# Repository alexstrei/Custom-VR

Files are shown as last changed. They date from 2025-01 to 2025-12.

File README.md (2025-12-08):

# Custom DIY VR Headset

A fully open, 3D-printable VR headset featuring adjustable IPD, dual-display modules, and integration with **Monado**.  
This repository contains all 3D models, build instructions, and software setup steps required to assemble and run the headset.

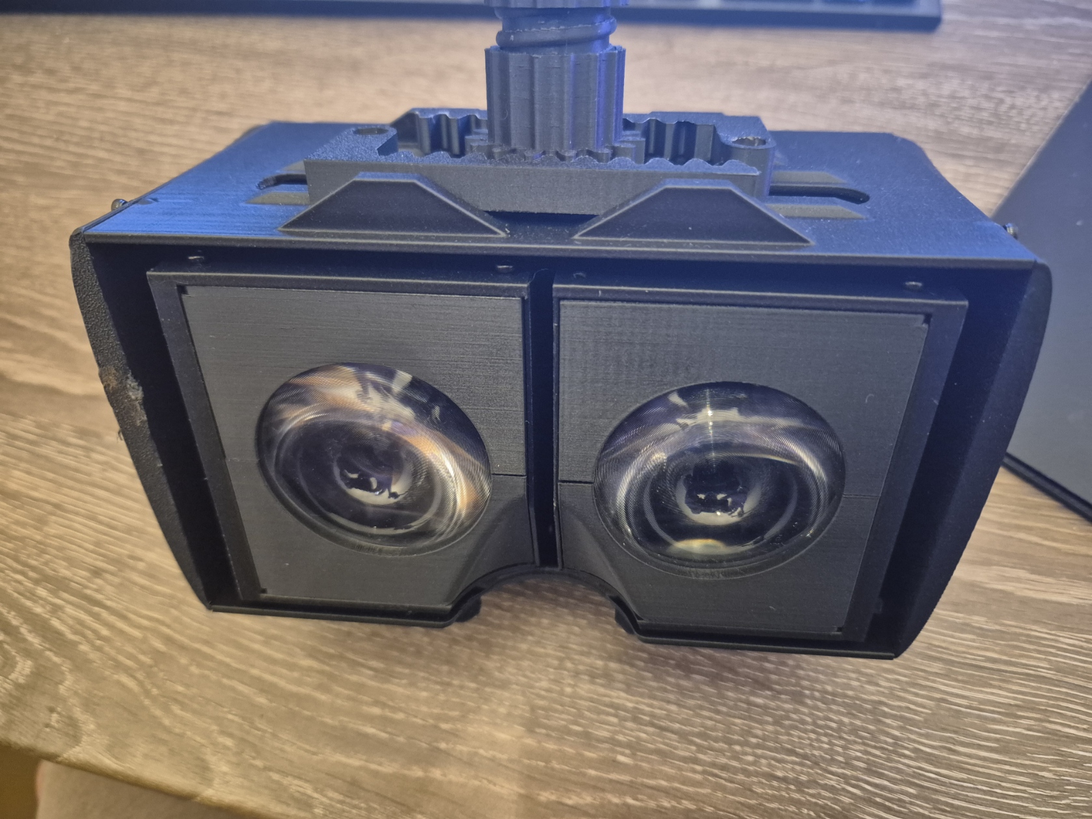
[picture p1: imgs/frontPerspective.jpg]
Front of the Headset


---

## Project Overview

This project provides:
- A **hardware design** for a custom VR headset  
- Integration of a **Custom VR** driver in Monado ([Original Project](https://gitlab.freedesktop.org/monado/monado)
---)
- Compiled binaries for [Basalt](https://github.com/CIFASIS/basalt-xr)
---

## Required Tools

 - 3D printer 
 - Metal saw 
 - Heat source (lighter, etc.)
 - Soldering iron

---

## Required Purchased Parts

These parts are used across the headset, primarily for the eye modules.

| Part | Count | Product ID | Vendor |
|---|---|---|---|
| Threaded Rod M3, 55 mm | 4 | B0D5DGMXNN | Amazon |
| Press Insert M3 | 4 | B0CRYWCYMG | Amazon |
| Allen Screw M2 x 4 mm | 40 | B0CKN2VK12 | Amazon |
| Press Insert M2 | 41 | B0CRYWCYMG | Amazon |
| Allen Screw M2 x 6 mm | 1 | B0CKN2VK12 | Amazon |
| Display + Breakout Board | 2 | 1005008477815602 | AliExpress |
| MIPI-to-HDMI Board | 2 | 1005008477815602 | AliExpress |

---

## Assembly 

An assembly video can be seen here: https://youtu.be/JpesEXfNubU but it still needs commentary.
Image of lens module can be seen here.
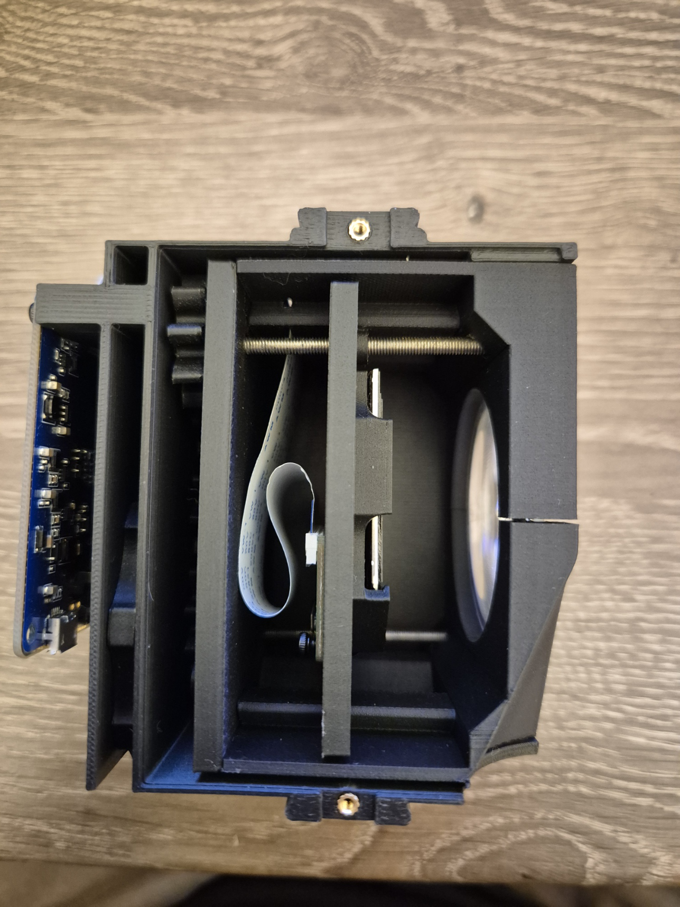
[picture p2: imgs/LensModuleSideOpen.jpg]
Lens Module


## Project Status

This is an experimental hardware project intended for research, education, and VR hacking.  
Contributions and improvements are welcome.

---

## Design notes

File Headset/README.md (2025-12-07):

# Printable Headset

The f3z file is for importing and editing the piece in Fusion360. The 3mf file is for 3D printing as it contains all the models.

# Images of the Final Headset

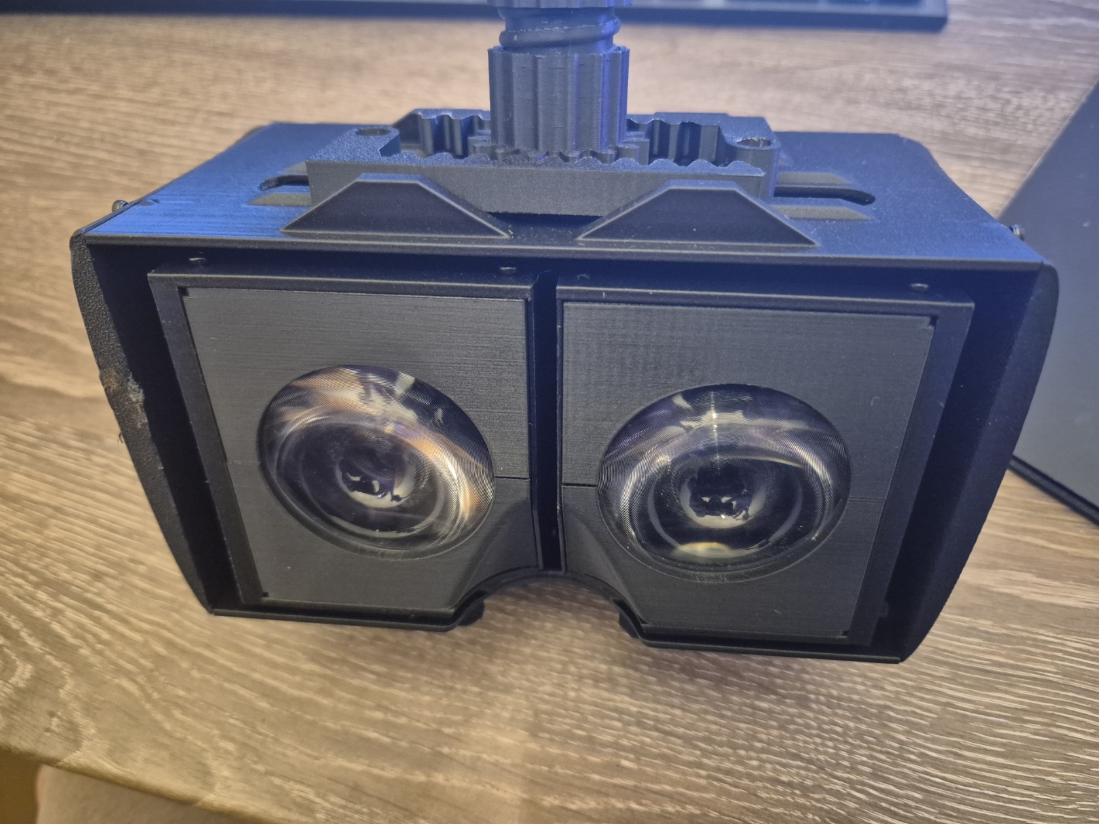
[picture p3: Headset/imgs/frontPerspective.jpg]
Full Headset

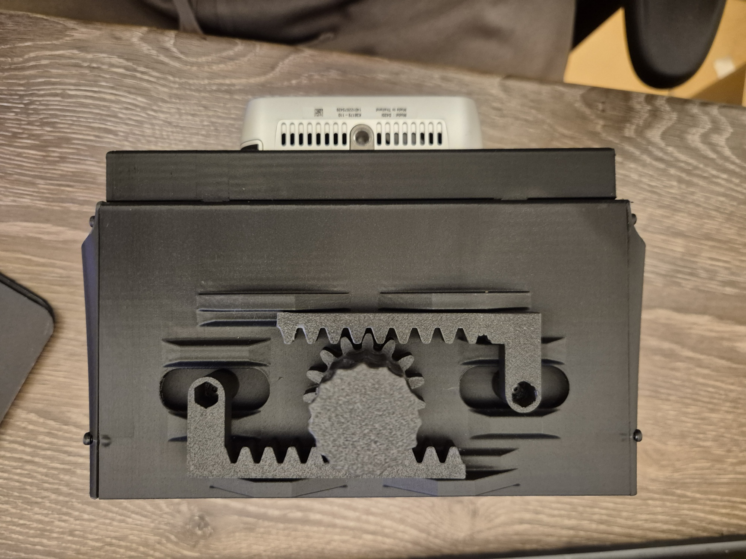
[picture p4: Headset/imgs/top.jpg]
Top of the Headset

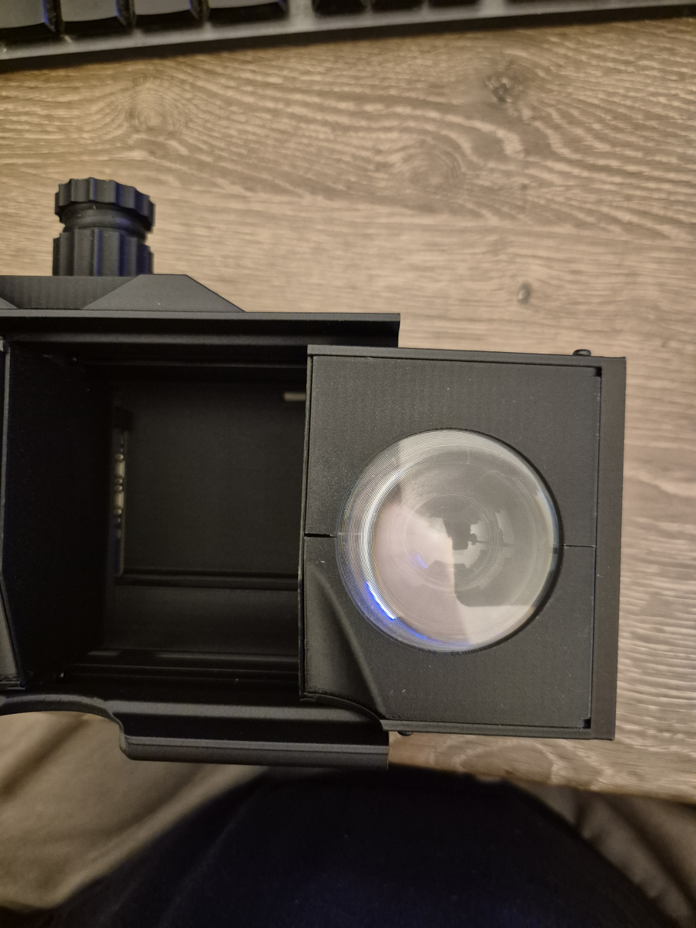
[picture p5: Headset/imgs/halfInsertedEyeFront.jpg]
Half inserted Eye module

Eye module

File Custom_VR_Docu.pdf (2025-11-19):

# Custom VR

This Document provides instructions for creating the custom VR headset described in the previous chapters. It begins by listing the required parts for each assembly step and provides detailed instructions for building the hardware. A description of the compilation process for Monado follows this. Since Monado does not run as expected by simply starting the program, the necessary environment variables are listed. Finally, if game support via SteamVR is desired, this chapter also includes an explanation of the required modifications.

## 1 Assembling the Headset

To create a new headset, a 3D printer, a Metal Saw, a lighter, or other source of heat, and a soldering iron are required. In Table 1, the parts that need to be purchased are listed. For 3D printing, a total of 39 parts need to be printed, 10 for each eye module, 8 for the case, and 1 for the electronics compartment. The assembly process is divided into two parts. The first describes the construction of the left eye module, which can also be used for the right eye module. For the second part, the full assembly of the case with the eye modules and the electronic compartment is described.

### 1.1 Eye Module

In Table 2, the required parts for the headset are listed, and in Figure 1, the 3D printed parts are listed and enumerated. The first step is to prepare the threaded rods. Using a metal saw, cut a 3mm deep line in the center of the

PartN | Count | Product ID
Threaded Rod M3 55mm | 4 | B0D5DGMXNN (Amazon)
Press Insert M3 | 4 | B0CRYWCYMG (Amazon)
Allen Screw M2 4mm | 40 | B0CKN2VK12 (Amazon)
Press Insert M2 | 41 | B0CRYWCYMG (Amazon)
Allen Screw M2 6mm | 1 | B0CKN2VK12 (Amazon)
Display with Breackoutboard | 2 | 1005008477815602 (AliExpress)
MIPI-to-HDMI Board | 2 | 1005008477815602 (AliExpress)

Table 1: Components which need to be bought with their corresponding Product ID and vendor

1

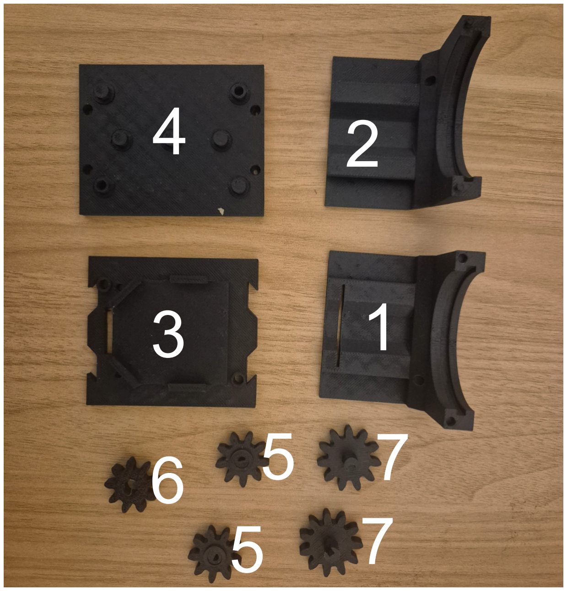
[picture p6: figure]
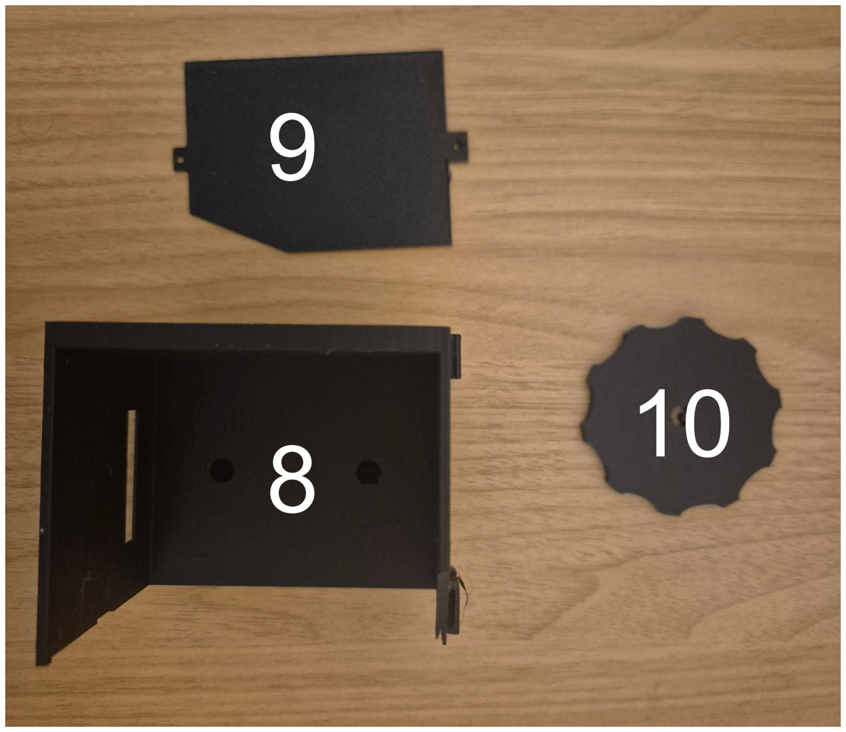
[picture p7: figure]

(a) Inner Module | (b) Outer Module

Figure 1: 3D printed Parts for the eye module with an enumeration

front side of the rod. This cut divides one end of the rod into two halves. Remove one half so that a 3 mm high semicircle remains, connected to the rest of the threaded rod. This semicircle is used to connect to part 5 and transfer the rotational movement from the gear to the threaded rod. By heating the cut end, the rod can be pressed into the semicircular hole in the center of part 5. The heated metal will slightly melt the plastic, allowing it to deform and form tightly around the metal for a secure fit. This process is done twice, once for each part 5. The press inserts can then be mounted on the 3D-printed parts. It is important to press them straight, otherwise the screws may sit crooked or, in the worst case, not fit at all. Parts 1 and 2 each require four M2 inserts, marked by small holes on the bottom and the side. Part 3 requires two M2 and two M3 inserts: M3 inserts for the threaded rods and M2 inserts for securing the breakout board. Part 8 requires six M2 inserts, three in the back for the MIPI-to-HDMI board, two to hold the side cover, and one in the top for the connection to the IPD mechanism.
With the preparations completed, the assembly can begin. First, the display is slid into the bracket in part 3 and the breakout board is mounted on the back.
Part | Count
3D Printed Parts | 10
Threaded Rod M3 55mm | 2
Press Insert M3 | 2
Allen Screw M2 4mm | 15
Press Insert M2 | 16
Display with Breackoutboard | 1
MIPI-to-HDMI Board | 1

Table 2: Parts for one Eye module

2

Part | Count
3D Printed Parts | 9
Allen Screw M2 4mm | 10
Press Insert M2 | 9
Allen Screw M2 6mm | 1

Table 3: Parts for one Eye module

The display and breakout board are then connected through the opening in part
3. Next, part 2 is prepared by placing the lens inside, and part 1 is placed on top of the lens. Part 2 must be positioned below part 1 because it has a small cutout to route the connection cable from the breakout board to the outside. The prepared part 3 is then slid into parts 1 and 2 using the dovetail slides. The connection cable passes through the slit, and part 4 is mounted on the back of parts 1 and 2 to secure the assembly, using four screws. Now, screw both part 5 gears with the threaded rod into the two holes of part 4, which should align with the M3 insert in part 3. Now, screw the gears in until the gears sit flush on part 4. Also, make sure that part 3 is not tilted and is parallel to the lens. Now place part 6 on the middle bump of part 4, and one part 7 on the bump above.
The parts of the surrounding shell are shown in Figure 1 b. This shell encloses the assembled module, blocks out external light, mounts the HDMIto-MIPI board, and connects the module to the main case. This is the most challenging part of the assembly process.
First, part 10 is placed in the smaller compartment in the back of part 8 and secured through the hole with the second part 7 gear. The previously assembled module is then slid into the prepared part 8 with all gears already in place. During sliding, the cable must be routed through the opening on top of part 8. Once the module is almost fully inserted, there is a good chance that the part 7 gear holding part 10 will not align with the gears on part 4. By gently moving part 10 while pressing the assembly together, part 7 will engage correctly with the inner gear system.
Once aligned, the assembly is secured in place by inserting two screws into the top and bottom front of part 8, which are positioned directly above and below the lens. Then Part 9 is placed and screwed onto the side of the module, sealing the shell. For the final step, the HDMI-to-MIPI board is mounted to the back of the assembly, and the cable from the breakout board is connected. The eye module is now fully assembled and ready for use. To build the module for the opposite side, the same steps are followed, but the process is mirrored.

### 1.2 Case and Electronics Compartment

In Table 3, the required parts for the case are listed, and the required 3D printed parts are enumerated in Figure 2. As with previous assemblies, the first step is

3

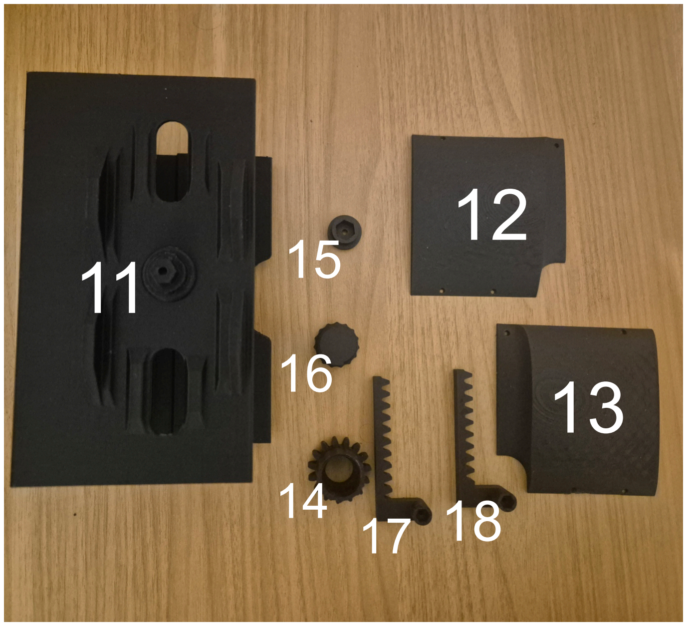
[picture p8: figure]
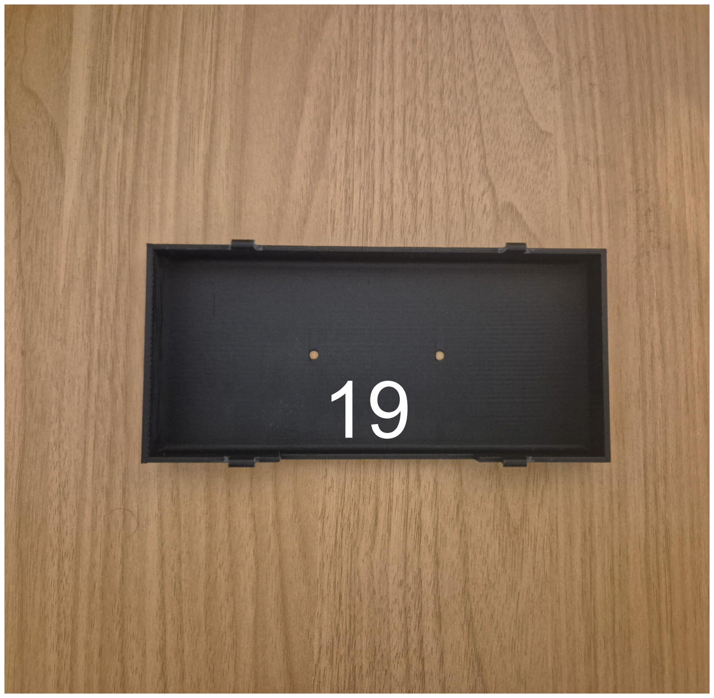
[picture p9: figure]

19 (a) Case Parts | (b) Electronics Compartment

Figure 2: 3D printed Parts for the case and the Electronics Compartment

to prepare the parts for mounting. This means inserting all necessary threaded inserts before doing any other work. In this case, only part 11 requires threaded inserts. Four inserts are needed on each side to mount the side panels, and one insert is placed on top, centered on the bump. With this, the preparation for the case assembly is complete.
First, the two eye modules are inserted into the left and right sides of part
11. To secure them, the left and right panels (parts 12 and 13) are mounted on their respective sides. It is important to check that both modules can move freely and do not bind to the dovetail slides during adjustment.
For the IPD adjustment mechanism, part 17 is placed on top of the device. The higher side is inserted through the left hole and onto the top of the left eye module, where a hexagonal knob serves as the mounting point. The same process is repeated on the right side with part 18. Each connection point is secured with an M2 × 4 mm screw. After moving both modules so that they meet in the center, part 14 is placed on the center bump at the top of the case, enabling synchronized movement of both modules by turning the gear. Next, part 15 is inserted and fixed using an M2 × 6 mm screw, which is threaded into the prepared insert—this is the only step that uses a different screw size. Then, part 16 is screwed into part 14 so that, when tightened, it presses against part 15 and creates a friction joint. Because part 15 has a hexagonal connection point, it cannot rotate, which ensures that the entire IPD mechanism is locked in place. Part 19 can be clipped on the backside of the device. It features two holes in which a camera can be mounted. The headset is now fully assembled and can be plugged into a PC with HDMI and USB cables.

## 2 Compiling Monado for Windows

The first challenge to overcome is compiling Monado for Windows. For this, the Visual Studio 2022 compiler (MSVC) and the CMake build system were

4

installed and used. For dependency management, VCPKG should be used. It is a cross-platform package manager for C++ dependencies. Fortunately, VCPKG is fully integrated into the project, so CMake handles dependency management. The required dependencies for Windows are illustrated in Table 4.
With this in place, CMake successfully generates the project files, allowing the build process to begin. However, this leads to compilation errors, as the entire project was originally based on a Linux compiler. Unfortunately, the standard libraries differ slightly, which caused the initial compilation to fail due to M PI being undefined. This issue can be quickly resolved by adding the line: #define M PI (3.14159265358979323846). After this addition, the compilation process completes successfully, and the system can be started for the first time.

## 3 Starting the System

By building and executing the ”monado service” target, the service can be started and used. However, at this stage, neither a device instance is created nor is the camera detected correctly. The reason for this is the absence of certain required environment variables (see Table 5).
The first variable is responsible for creating an instance of the custom VR device on startup. This is achieved by disabling automatic probing and implicitly registering the device in the system. The second variable is required for the RealSense driver. To correctly identify the connected cameras, the prober must be assigned a valid source index. Without this, the system crashes during startup due to missing stream configuration parameters.
For the SLAM library, two additional environment variables are necessary. One defines the path to the SLAM library, in this case the Basalt library. The other specifies the configuration file for the D435i. Basalt requires this configuration file to operate correctly, as it contains essential parameters such as camera intrinsics, resolution, IMU biases, standard deviations, and other calibration data. These values can be extracted from the camera itself using the RealSense
Dependecie name | Description
Eigen 3.x | linear algebra library
Pthreads Windows | POSIX threading header for Windows
SDL | access to mouse, keyboard, and other peripherals
Vulkan | Graphic API
HIDAPI | Bluetooth and USB interface
LibUSB | For USB device access
cJSON | JSON parser for C
WIL | For easier Windows development

Table 4: This Table lists the required dependencies for Monado along with a brief description of their general purpose. These dependencies must be installed to allow CMake to generate the necessary build files successfully.

5

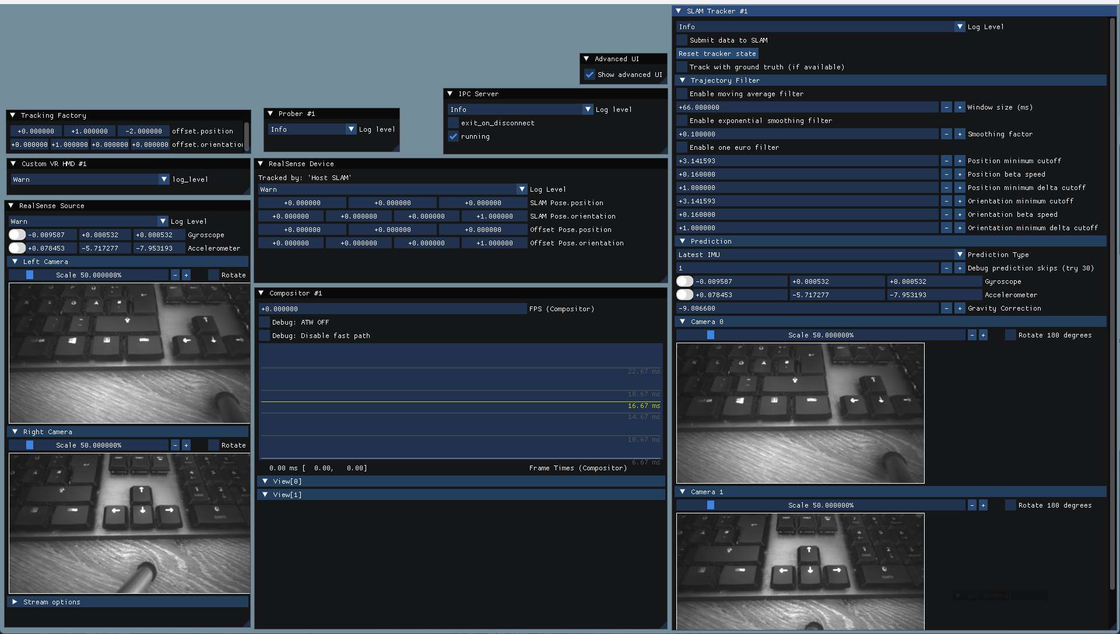
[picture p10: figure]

Figure 3: This image shows the monado UI consisting of multiple windows.

Name | Value
CUSTOM VR ENABLE | 1
RS SOURCE INDEX | 0
SLAM CONFIG | ./d435i.toml
VIT SYSTEM LIBRARY PATH | ./basalt.dll
XRT DEBUG GUI | 1

Table 5: Environment variables for starting monado properly. The first one is for instantiating the headset. Second for the streaming index of the camera, third and fourth for the slam configuration and the last one to enable the debug gui.

camera calibration tool. For the IMU-specific statistical values, a pre-generated configuration file tailored for the D435i was used. The last environment variable enables the use of the debug GUI, shown in Figure 3. This interface was created using ImuGUI and provides controls and statistics for various features within Monado. Several windows within the UI are handy and have been frequently utilized during development.

## 4 Configuring Environment

To inform OpenXR runtime that our platform exists and that we intend to use it
as our standard value, the registry must be edited. In Computer\HKEY LOCAL MACHINE \SOFTWARE\Khronos\OpenXR\1 the path to the file openxr monado-dev.json
must be set. This file is generated during the application build and resides in

6

the binaries directory. It has all the necessary values for the OpenXR loader to load an OpenXR application with the Monado runtime.
With this setup, it is possible to start VR programs from Unity, which then are displayed by Monado. For Steam gaming, there is a bit more setup involved. First of all, the Steam plugin needs to be compiled.
This is done by compiling the ”driver monado” target. This creates a new file in the steamvr-monado/bin including the monado driver.dll which is the plugin for Steam. With this plugin, the driver now needs to be registered on Steam. This is done with a separate batch file that is shipped with the application. ./steam/steamapps/common/SteamVR/bin/vrpathreg.sh adddriver C:/path/to/dll/monado\_driver.dll let Steam know where the custom VR driver is. The success of the command can be verified by running vrpathreg.sh without any parameters. This enables the use of all hardware supported by Monado on Steam, but does not allow for playing games.
To enable game support, the OpenComposite application must be installed. It is responsible for forwarding the SteamVR calls to OpenXR. wBy starting the program and clicking on the ”Switch to OpenVR” button, the redirect is set in place. For the last step, a file in the game needs to be changed to work. Somewhere in the game directory, there is a file called openvr api.dll . The OpenComposite repository provides a replacement file that needs to be swapped out in the game files. With this in place, Monado can be booted up, and then the game can start. This should now open the rendered window. The window can now be placed on top of the two displays to see the rendered view in the headset.

7

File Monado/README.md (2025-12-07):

# Copy of Monado - XR Runtime (XRT)

<!--
Copyright 2018-2021, Collabora, Ltd.

SPDX-License-Identifier: CC-BY-4.0

This must stay in sync with the last section!
-->
This project is copied from Monado (links are below) and modified by myself.

Please note 
> * Main homepage and documentation: <https://monado.freedesktop.org/>
> * Promotional homepage: <https://monado.dev>
> * Maintained at <https://gitlab.freedesktop.org/monado/monado>
> * Latest API documentation: <https://monado.pages.freedesktop.org/monado>
> * Continuously-updated changelog of the default branch:
>   <https://monado.pages.freedesktop.org/monado/_c_h_a_n_g_e_l_o_g.html>

Monado is an open source XR runtime delivering immersive experiences such as VR
and AR on mobile, PC/desktop, and any other device
(because gosh darn people
come up with a lot of weird hardware).
Monado aims to be a complete and conforming implementation
of the OpenXR API made by Khronos.
The project is primarily developed on GNU/Linux, but also runs on Android and Windows.
"Monado" has no specific meaning and is just a name.

## Monado source tree

* `src/xrt/include` - headers that define the internal interfaces of Monado.
* `src/xrt/compositor` - code for doing distortion and driving the display hardware of a device.
* `src/xrt/auxiliary` - utilities and other larger components.
* `src/xrt/drivers` - hardware drivers.
* `src/xrt/state_trackers/oxr` - OpenXR API implementation.
* `src/xrt/targets` - glue code and build logic to produce final binaries.
* `src/external` - a small collection of external code and headers.

## Getting Started

Dependencies include:

* [CMake][] 3.13 or newer (Note Ubuntu 18.04 only has 3.10)
* Python 3.6 or newer
* Vulkan headers and loader - Fedora package `vulkan-loader-devel`
* OpenGL headers
* Eigen3 - Debian/Ubuntu package `libeigen3-dev`
* glslangValidator - Debian/Ubuntu package `glslang-tools`, Fedora package `glslang`.
* libusb
* libudev - Debian/Ubuntu package `libudev-dev`, Fedora package `systemd-devel`
* Video 4 Linux - Debian/Ubuntu package `libv4l-dev`.

Optional (but recommended) dependencies:

* libxcb and xcb-xrandr development packages
* [OpenHMD][] 0.3.0 or newer (found using pkg-config)

Truly optional dependencies, useful for some drivers, app support, etc.:

* Doxygen - Debian/Ubuntu package `doxygen` and `graphviz`
* Wayland development packages
* Xlib development packages
* libhidapi - Debian/Ubuntu package `libhidapi-dev`
* OpenCV
* libuvc - Debian/Ubuntu package `libuvc-dev`
* libjpeg
* libbluetooth - Debian/Ubuntu package `libbluetooth-dev`
* libsdl - Debian/Ubuntu package `libsdl2-dev`

Experimental Windows support requires the Vulkan SDK and also needs or works
best with the following vcpkg packages installed:

* pthreads eigen3 libusb hidapi zlib doxygen

If you have a recent [vcpkg](https://vcpkg.io) installed and use the appropriate
CMake toolchain file, the vcpkg manifest in the Monado repository will instruct
vcpkg to locally install the dependencies automatically. The Vulkan SDK
installer should set the `VULKAN_SDK` Windows environment variable to point
at the installation location (for example, `C:/VulkanSDK/1.3.250.1`), though
make sure you open a new terminal (or open the CMake GUI) *after* doing that
install to make sure it is available.

Monado has been tested on these distributions, but is expected to work on almost
any modern distribution.

* Ubuntu 24.04, 22.04, 20.04, (18.04 may not be fully supported)
* Debian 11 `bookworm`, 10 `buster`
  * Up-to-date package lists can be found in our CI config file,
    `.gitlab-ci.yml`
* Archlinux

These distributions include recent-enough versions of all the
software to use direct mode,
without using any external, third-party, or backported
package sources.

See also [Status of DRM Leases][drm-lease]
for more details on specific packages, versions, and commits.

Due to the lack of a OpenGL extension: GL_EXT_memory_object_fd on Intel's
OpenGL driver, only the AMD
radeonsi driver and the proprietary NVIDIA driver will work for OpenGL OpenXR
clients. This is due to a requirement of the Compositor. Support status of the
extension can be found on the [mesamatrix website][mesamatrix-ext].

### CMake

Build process is similar to other CMake builds,
so something like the following will build it.

Go into the source directory, create a build directory,
and change into it.

```bash
mkdir build
cd build
```

Then, invoke [CMake to generate a project][cmake-generate].
Feel free to change the build type or generator ("Ninja" is fast and parallel) as you see fit.

```bash
cmake .. -DCMAKE_BUILD_TYPE=Debug -G "Unix Makefiles"
```

If you plan to install the runtime,
append something like `-DCMAKE_INSTALL_PREFIX=~/.local`
to specify the root of the install directory.
(The default install prefix is `/usr/local`.)

To build, [the generic CMake build commands][cmake-build] below will work on all systems,
though you can manually invoke your build tool (`make`, `ninja`, etc.) if you prefer.
The first command builds the runtime and docs,
and the second, which is optional, installs the runtime under `${CMAKE_INSTALL_PREFIX}`.

```bash
cmake --build .
cmake --build . --target install
```

Alternately, if using Make, the following will build the runtime and docs, then install.
Replace `make` with `ninja` if you used the Ninja generator.

```bash
make
make install
```

Documentation can be browsed by opening `doc/html/index.html` in the build directory in a web browser.

## Getting started using OpenXR with Monado

This implements the [OpenXR][] API,
so to do anything with it, you'll need an application
that uses OpenXR, along with the OpenXR loader.
The OpenXR loader is a glue library that connects OpenXR applications to OpenXR runtimes such as Monado
It determines which runtime to use by looking for the config file `active_runtime.json` (either a symlink to
or a copy of a runtime manifest) in the usual XDG config paths
and processes environment variables such as `XR_RUNTIME_JSON=/usr/share/openxr/0/openxr_monado.json`.
It can also insert OpenXR API Layers without the application or the runtime having to do it.

You can use the `hello_xr` sample provided with the OpenXR SDK.

The OpenXR loader can be pointed to a runtime json file in a nonstandard location with the environment variable `XR_RUNTIME_JSON`. Example:

```bash
XR_RUNTIME_JSON=~/monado/build/openxr_monado-dev.json ./openxr-example
```

For ease of development Monado creates a runtime manifest file in its build directory using an absolute path to the
Monado runtime in the build directory called `openxr_monado-dev.json`. Pointing `XR_RUNTIME_JSON` to this
file allows using Monado after building, without installing.

Note that the loader can always find and load the runtime
if the path to the runtime library given in the json manifest is an absolute path,
but if a relative path like `libopenxr_monado.so.0` is given,
then `LD_LIBRARY_PATH` must include the directory that contains `libopenxr_monado.so.0`.
The absolute path in `openxr_monado-dev.json` takes care of this for you.

Distribution packages for monado may provide the  "active runtime" file `/etc/xdg/openxr/1/active_runtime.json`.
In this case the loader will automatically use Monado when starting an OpenXR application. This global configuration
can be overridden on a per user basis by creating `~/.config/openxr/1/active_runtime.json`.

## Direct mode

On AMD and Intel GPUs our direct mode code requires a connected HMD to have
the `non-desktop` xrandr property set to 1.
Only the most common HMDs have the needed quirks added to the linux kernel.

If you know that your HMD lacks the quirk you can run this command **before** or
after connecting the HMD and it will have it. Where `HDMI-A-0` is the xrandr
output name where you plug the HMD in.

```bash
xrandr --output HDMI-A-0 --prop --set non-desktop 1
```

You can verify that it stuck with the command.

```bash
xrandr --prop
```

## Running Vulkan Validation

To run Monado with Vulkan validation the loader's layer functionality can be used.
```
VK_INSTANCE_LAYERS=VK_LAYER_KHRONOS_validation ./build/src/xrt/targets/service/monado-service
```
The same can be done when launching a Vulkan client.

If you want a backtrace to be produced at validation errors, create a `vk_layer_settings.txt`
file with the following content:
```
khronos_validation.debug_action = VK_DBG_LAYER_ACTION_LOG_MSG,VK_DBG_LAYER_ACTION_BREAK
khronos_validation.report_flags = error,warn
khronos_validation.log_filename = stdout
```

## Coding style and formatting

[clang-format][] is used,
and a `.clang-format` config file is present in the repo
to allow your editor to use them.

To manually apply clang-format to every non-external source file in the tree,
run this command in the source dir with a `sh`-compatible shell
(Git for Windows git-bash should be OK):

```bash
scripts/format-project.sh
```

You can optionally put something like `CLANG_FORMAT=clang-format-7` before that command
if your clang-format binary isn't named `clang-format`.
**Note that you'll typically prefer** to use something like `git clang-format`
to re-format only your changes, in case version differences in tools result in overall format changes.
The CI "style" job currently runs on Debian Bullseye, so it has clang-format-11.

[OpenHMD]: http://openhmd.net
[drm-lease]: https://haagch.frickel.club/#!drmlease%2Emd
[OpenXR]: https://khronos.org/openxr
[clang-format]: https://releases.llvm.org/7.0.0/tools/clang/docs/ClangFormat.html
[cmake-build]: https://cmake.org/cmake/help/v3.12/manual/cmake.1.html#build-tool-mode
[cmake-generate]: https://cmake.org/cmake/help/v3.12/manual/cmake.1.html
[CMake]: https://cmake.org
[mesamatrix-ext]: https://mesamatrix.net/#Version_ExtensionsthatarenotpartofanyOpenGLorOpenGLESversion

## Contributing, Code of Conduct

See `CONTRIBUTING.md` for details of contribution guidelines. GitLab Issues and
Merge Requests are the preferred way to discuss problems, suggest enhancements,
or submit changes for review. **In case of a security issue**, you should choose
the "confidential" option when using the GitLab issues page. For highest
security, you can send encrypted email (using GPG/OpenPGP) to Rylie Pavlik at
<rylie.pavlik@collabora.com> and using the associated key from
<https://keys.openpgp.org/vks/v1/by-fingerprint/45207B2B1E53E1F2755FF63CC5A2D593A61DBC9D>.

Please note that this project is released with a Contributor Code of Conduct.
By participating in this project you agree to abide by its terms.

We follow the standard freedesktop.org code of conduct,
available at <https://www.freedesktop.org/wiki/CodeOfConduct/>,
which is based on the [Contributor Covenant](https://www.contributor-covenant.org).

Instances of abusive, harassing, or otherwise unacceptable behavior may be
reported by contacting:

* First-line project contacts:
  * Rylie Pavlik <rylie.pavlik@collabora.com>
  * Frederic Plourde <frederic.plourde@collabora.com>
  * Jakob Bornecrantz <tbornecrantz@nvidia.com>
* freedesktop.org contacts: see most recent list at <https://www.freedesktop.org/wiki/CodeOfConduct/>

Code of Conduct section excerpt adapted from the
[Contributor Covenant](https://www.contributor-covenant.org), version 1.4.1,
available at
<https://www.contributor-covenant.org/version/1/4/code-of-conduct.html>, and
from the freedesktop.org-specific version of that code, available at
<https://www.freedesktop.org/wiki/CodeOfConduct/>, used under CC-BY-4.0.

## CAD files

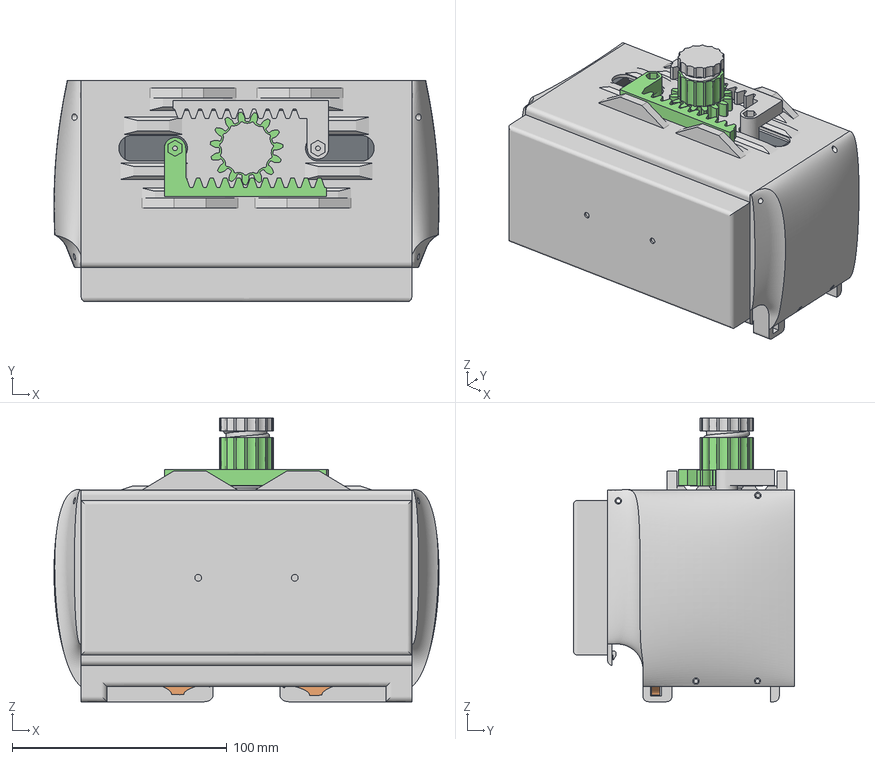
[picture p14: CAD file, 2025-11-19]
Headset/VR Glasses.3mf
179.4 x 103.2 x 132.1 mm
BackCover x 2
Körper1 x 29
Körper14
Körper2
Körper3
Körper4
LensHolder Right Bottom (1) x 2
LensHolderBottom x 2
LenseMoutingplate x 2

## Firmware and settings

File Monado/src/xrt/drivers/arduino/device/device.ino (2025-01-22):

// Copyright 2019-2020, Collabora, Ltd.
// SPDX-License-Identifier: BSL-1.0
/*!
 * @file
 * @brief  Arduino based felxable input device code.
 * @author Pete Black <pete.black@collabora.com>
 * @author Jakob Bornecrantz <jakob@collabora.com>
 * @ingroup drv_arduino
 */

#include "mbed.h"
#include <stdint.h>
#include <ArduinoBLE.h>
#include <Arduino_LSM9DS1.h>


#define USE_SERIAL
#ifdef USE_SERIAL
#define LOG(...) Serial.print(__VA_ARGS__)
#define LOG_LN(...) Serial.println(__VA_ARGS__)
#else
#define LOG(...) (void)NULL
#define LOG_LN(...) (void)NULL
#endif

#define SET(o, v)                                                              \
	do {                                                                   \
		uint32_t val = v;                                              \
		buffer[o + 0] = val >> 8;                                      \
		buffer[o + 1] = val;                                           \
	} while (false)

struct Sample
{
	int32_t acc_x = 0;
	int32_t acc_y = 0;
	int32_t acc_z = 0;
	int32_t gyr_x = 0;
	int32_t gyr_y = 0;
	int32_t gyr_z = 0;
	uint32_t time = 0;
};


/*
 *
 * Global variables
 *
 */

volatile bool isConnected;

BLEService service("00004242-0000-1000-8000-004242424242"); // create service

// create switch characteristic and allow remote device to read and write
BLECharacteristic notify("00000001-1000-1000-8000-004242424242",
                         BLERead | BLENotify,
                         20,
                         true);

rtos::Mutex mutex;
rtos::Thread thread;
rtos::Mail<Sample, 100> mail;


/*
 *
 * IMU functions.
 *
 */

void
imu_loop()
{
	if (isConnected == false) {
		return;
	}

	if (IMU.accelerationAvailable() && IMU.gyroscopeAvailable()) {
		uint32_t time = micros();
		float gyr_x, gyr_y, gyr_z;
		float acc_x, acc_y, acc_z;
		IMU.readGyroscope(gyr_x, gyr_y, gyr_z);
		IMU.readAcceleration(acc_x, acc_y, acc_z);

		Sample *sample = mail.alloc();
		sample->time = time;
		sample->acc_x = acc_x * (32768.0 / 4.0);
		sample->acc_y = acc_y * (32768.0 / 4.0);
		sample->acc_z = acc_z * (32768.0 / 4.0);

		sample->gyr_x = gyr_x * (32768.0 / 2000.0);
		sample->gyr_y = gyr_y * (32768.0 / 2000.0);
		sample->gyr_z = gyr_z * (32768.0 / 2000.0);
		mail.put(sample);
	}
}

void
imu_thread()
{
	while (true) {
		imu_loop();
		delay(1);
	}
}


/*
 *
 * BLE functions.
 *
 */

void
loop()
{
	bool got_mail = false;
	int32_t acc_x = 0, acc_y = 0, acc_z = 0;
	int32_t gyr_x = 0, gyr_y = 0, gyr_z = 0;
	int32_t count = 0;
	uint32_t time;

	uint8_t buffer[20];
	static int countPacket = 0;

	BLE.poll();
	if (isConnected == false) {
		return;
	}

	while (true) {
		osEvent evt = mail.get(0);
		if (evt.status != osEventMail) {
			break;
		}

		Sample *sample = (Sample *)evt.value.p;
		acc_x += sample->acc_x;
		acc_y += sample->acc_y;
		acc_z += sample->acc_z;
		gyr_x += sample->gyr_x;
		gyr_y += sample->gyr_y;
		gyr_z += sample->gyr_z;
		time = sample->time;
		mail.free(sample);

		count++;
		got_mail = true;
	}

	if (!got_mail) {
		delay(1);
		return;
	}

	buffer[0] = countPacket++;
	buffer[1] = count;
	buffer[2] = 0;

	buffer[3] = time >> 16;
	buffer[4] = time >> 8;
	buffer[5] = time;

	SET(6, (acc_x / count));
	SET(8, (acc_y / count));
	SET(10, (acc_z / count));
	SET(12, (gyr_x / count));
	SET(14, (gyr_y / count));
	SET(16, (gyr_z / count));
	buffer[18] = 0;
	buffer[19] = 0;

	notify.writeValue(buffer, 20);
}

void
ble_peripheral_connect_handler(BLEDevice peer)
{
	LOG("Connected event, central: ");
	LOG_LN(peer.address());
	isConnected = true;
	BLE.poll();
}

void
ble_peripheral_disconnect_handler(BLEDevice peer)
{
	LOG("Disconnected event, central: ");
	LOG_LN(peer.address());
	isConnected = false;
	BLE.poll();
}


/*
 *
 * Main functions.
 *
 */

void
block()
{
	while (true) {
		LOG_LN("BLOCKED");
		delay(1000);
	}
}

void
setup()
{
#ifdef USE_SERIAL
	Serial.begin(9600);
	while (!Serial) {
	}
#endif

	if (!BLE.begin()) {
		LOG_LN("BLE initialisation failed!");
		block();
	}

	if (!IMU.begin()) {
		LOG_LN("IMU initialisation failed!");
		block();
	}

	BLE.setLocalName("Monado Flexible Controller");
	BLE.setAdvertisedService(service);
	service.addCharacteristic(notify);
	BLE.addService(service);

	// Assign event handlers for connected, disconnected to peripheral.
	BLE.setEventHandler(BLEConnected, ble_peripheral_connect_handler);
	BLE.setEventHandler(BLEDisconnected, ble_peripheral_disconnect_handler);

	notify.setValue(0);

	// Start advertising.
	BLE.advertise();

	isConnected = false;

	// IMU has its own thread.
	thread.start(imu_thread);
}

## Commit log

2025-01-22 added sample hmd
2025-11-19 Added Readme and Headset Files
    [VR Glasses.3mf]
2025-12-08 Fix image link for Lens Module in README
